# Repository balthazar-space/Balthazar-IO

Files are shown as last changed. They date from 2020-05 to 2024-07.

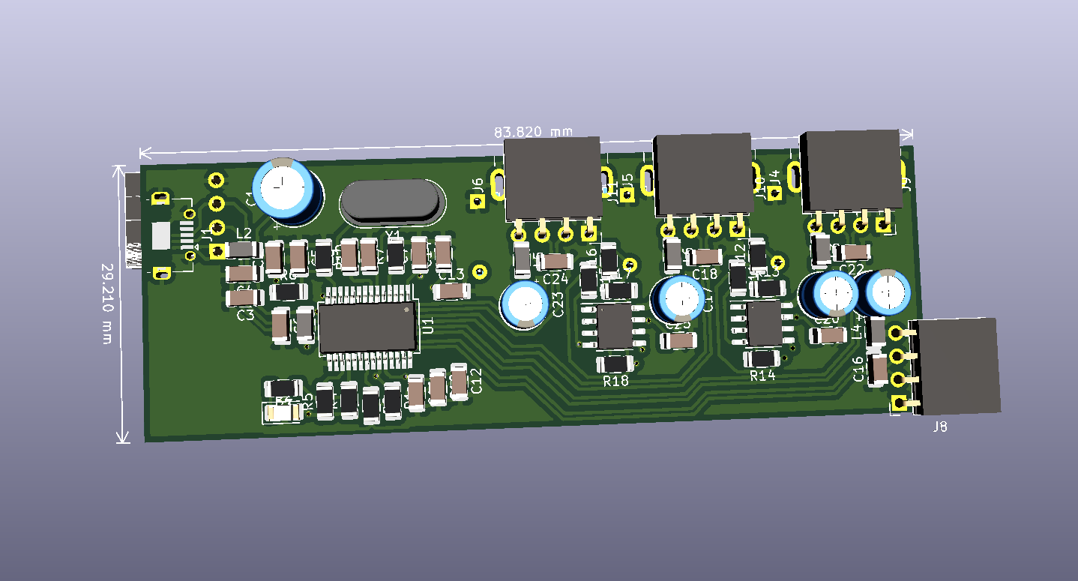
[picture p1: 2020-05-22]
images/BalthazarIO_3.png

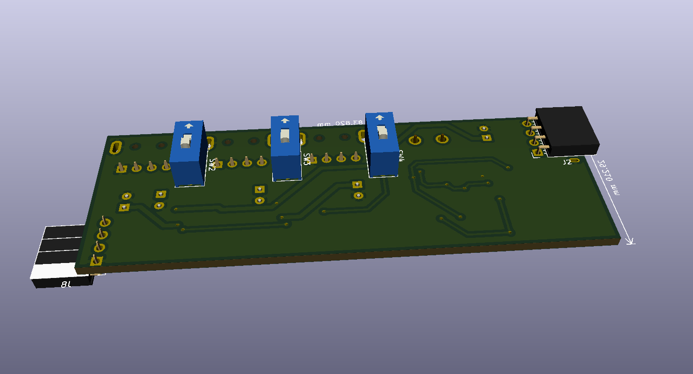
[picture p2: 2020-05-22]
images/BalthazarIO_6.png

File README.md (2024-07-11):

# Balthazar

Open-hardware laptop computer modules description and concept.

These are electronic schematic modules as presented at https://balthazar.space/wiki/Balthazar with the main aim for team access. See the [main repository](https://github.com/balthazar-space/balthazar) for other designs.

# Balthazar IO

BalthazarIO module is a simple USB2.0 four-port hub for the internal devices: keyboard and touchpad, webcam and optional audiocard. Additional simplification and pcb size reduction was done recently.

IO-board (here) means connectivity with peripheral devices. These can be seen as on-board and out-board. On-board Balthazar devices include: combined usb1.1 keyboard + trackpad, usb2.0 webcam and optional audio-card. 

Since we are targeting the mini-computer family of systems (Raspberry PI. Banana PI, Orange PI, ...) - USB is the usual solution for this. 

A simple usb 2.0 hub is enough, so a very ubiquitous usb hub chip was chosen. Main mini-computer board usually provides a much better hub for 4 downstream usb devices. At this point this is still mainly USB 2.x - slowly moving to usb3.x.

Mass storage / system disk - microSD – and especially versions of SSD (sata or pcie) – should be plugged to usb3.x directly (via usb adapter).

KiCad 5.1.5 files are uploaded here as well as the drawings and pictures.

## License

All resources licensed under the CERN Open Hardware Licence CERN-OHL W V.2.0

Version 2.0 of the CERN-OHL introduces three variants of the licence – strongly (S) reciprocal, weakly (W) reciprocal and permissive (P) – which aim to address specific constraints caused by different collaboration models currently used in open-hardware projects. 

The first two variants mean that if any product is made using an open hardware design, the design of that product, including any improvements or modifications, should be made available under the same licence as that of the original product. Permissive licences do not impose this condition.

See the [LICENSE.md](./LICENSE.md) file for more information.

## Funding

This project is funded through the [NGI Zero Entrust Fund](https://nlnet.nl/entrust), a fund
established by [NLnet](https://nlnet.nl) with financial support from the European Commission's
[Next Generation Internet](https://ngi.eu) program. Learn more on the [NLnet project page](https://nlnet.nl/project/Balthazar-Casing/).

[NLNet foundation logo](https://nlnet.nl)
[NGI0 Entrust Logo](https://nlnet.nl/entrust)

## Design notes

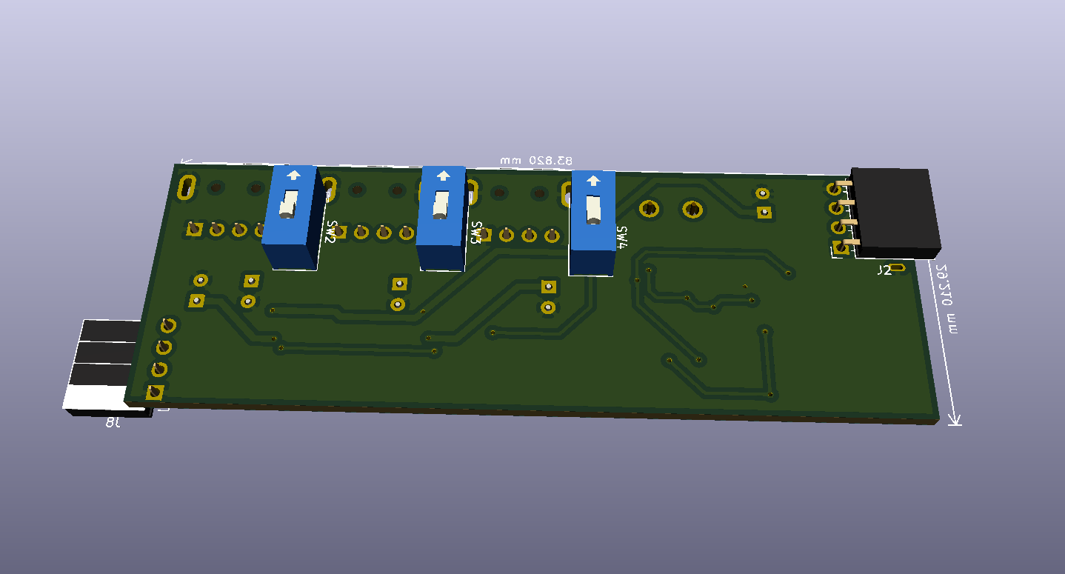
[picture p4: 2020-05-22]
images/BalthazarIO_4.png

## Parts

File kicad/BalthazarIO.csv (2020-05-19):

Reference | Value | Footprint | Datasheet
C7 | 100n | Capacitor_SMD:C_1206_3216Metric | ~
C6 | 100n | Capacitor_SMD:C_1206_3216Metric | ~
C4 | 100n | Capacitor_SMD:C_1206_3216Metric | ~
L1 | 10uH | Inductor_SMD:L_1206_3216Metric
C11 | 100n | Capacitor_SMD:C_1206_3216Metric | ~
C12 | 100n | Capacitor_SMD:C_1206_3216Metric | ~
C13 | 100n | Capacitor_SMD:C_1206_3216Metric | ~
C14 | 100n | Capacitor_SMD:C_1206_3216Metric | ~
R7 | 680 | Resistor_SMD:R_1206_3216Metric | ~
Y1 | Crystal 12MHz | Crystal:Crystal_HC50_Vertical | ~
C8 | 22-33p | Capacitor_SMD:C_1206_3216Metric | ~
C9 | 22-33p | Capacitor_SMD:C_1206_3216Metric | ~
J5 | USB_A | Connector_USB:USB_A_CNCTech_1001-011-01101_Horizontal | ~
J4 | USB_A | Connector_USB:USB_A_CNCTech_1001-011-01101_Horizontal | ~
J6 | USB_A | Connector_USB:USB_A_CNCTech_1001-011-01101_Horizontal | ~
J3 | USB_A | Connector_USB:USB_A_CNCTech_1001-011-01101_Horizontal | ~
C5 | 0.1-1u | Capacitor_SMD:C_1206_3216Metric | ~
R5 | 10K-510K-1M | Resistor_SMD:R_1206_3216Metric | ~
R4 | 100K | Resistor_SMD:R_1206_3216Metric | ~
R3 | 1K | Resistor_SMD:R_1206_3216Metric | ~
D2 | LED GREEN | LED_SMD:LED_1206_3216Metric | ~
R1 | 5K1 | Resistor_SMD:R_1206_3216Metric | ~
R2 | 10K | Resistor_SMD:R_1206_3216Metric | ~
C2 | 1u | Capacitor_SMD:C_1206_3216Metric | ~
C1 | 330uF | Capacitor_THT:CP_Radial_D8.0mm_P2.50mm | ~
F1 | 500mA | Fuse:Fuse_1206_3216Metric | ~
C18 | 100n | Capacitor_SMD:C_1206_3216Metric | ~
C17 | 100uF | Capacitor_THT:CP_Radial_D6.3mm_P2.50mm | ~
C16 | 100n | Capacitor_SMD:C_1206_3216Metric | ~
C15 | 100uF | Capacitor_THT:CP_Radial_D6.3mm_P2.50mm | ~
J2 | Conn_01x04_Female | Connector_PinSocket_2.54mm:PinSocket_1x04_P2.54mm_Horizontal | ~
C10 | 10uF | Capacitor_SMD:C_1206_3216Metric | ~
C3 | 10uF | Capacitor_SMD:C_1206_3216Metric | ~
L4 | 10uH | Inductor_SMD:L_1206_3216Metric
L5 | 10uH | Inductor_SMD:L_1206_3216Metric
L3 | 10uH | Inductor_SMD:L_1206_3216Metric
R6 | 10K | Resistor_SMD:R_1206_3216Metric | ~
R10 | 47K | Resistor_SMD:R_1206_3216Metric | ~
U2 | AT24CS02-XHM | Package_SO:SOP-8_3.9x4.9mm_P1.27mm | http://ww1.microchip.com/downloads/en/DeviceDoc/Atmel-8815-SEEPROM-AT24CS01-02-Datasheet.pdf
C19 | 100n | Capacitor_SMD:C_1206_3216Metric | ~
R9 | 10K | Resistor_SMD:R_1206_3216Metric | ~
L6 | 10uH | Inductor_SMD:L_1206_3216Metric
C24 | 100n | Capacitor_SMD:C_1206_3216Metric | ~
C23 | 100uF | Capacitor_THT:CP_Radial_D6.3mm_P2.50mm | ~
C22 | 100n | Capacitor_SMD:C_1206_3216Metric | ~
C21 | 100uF | Capacitor_THT:CP_Radial_D6.3mm_P2.50mm | ~
J1 | USB_B_Micro | Connector_USB:USB_Micro-AB_Molex_47590-0001 | ~
L2 | ferrite | Inductor_SMD:L_1206_3216Metric
U3 | AIC1526-0 | Package_SO:SOP-8_3.9x4.9mm_P1.27mm
C20 | 100n | Capacitor_SMD:C_1206_3216Metric | ~
R14 | 10K | Resistor_SMD:R_1206_3216Metric | ~
R13 | 10K | Resistor_SMD:R_1206_3216Metric | ~
R12 | 100K | Resistor_SMD:R_1206_3216Metric | ~
R11 | 100K | Resistor_SMD:R_1206_3216Metric | ~
SW1 | SW_DIP_x01 | Button_Switch_THT:SW_DIP_SPSTx01_Slide_9.78x4.72mm_W7.62mm_P2.54mm | ~
SW2 | SW_DIP_x01 | Button_Switch_THT:SW_DIP_SPSTx01_Slide_9.78x4.72mm_W7.62mm_P2.54mm | ~
U4 | AIC1526-0 | Package_SO:SOP-8_3.9x4.9mm_P1.27mm
C25 | 100n | Capacitor_SMD:C_1206_3216Metric | ~
R18 | 10K | Resistor_SMD:R_1206_3216Metric | ~
R17 | 10K | Resistor_SMD:R_1206_3216Metric | ~
R16 | 100K | Resistor_SMD:R_1206_3216Metric | ~
R15 | 100K | Resistor_SMD:R_1206_3216Metric | ~
SW3 | SW_DIP_x01 | Button_Switch_THT:SW_DIP_SPSTx01_Slide_9.78x4.72mm_W7.62mm_P2.54mm | ~
SW4 | SW_DIP_x01 | Button_Switch_THT:SW_DIP_SPSTx01_Slide_9.78x4.72mm_W7.62mm_P2.54mm | ~
U1 | GL850G-28pin | Package_SO:SSOP-28_5.3x10.2mm_P0.65mm
J10 | USB_01x04 | Connector_PinSocket_2.54mm:PinSocket_1x04_P2.54mm_Horizontal | ~
J11 | USB_01x04 | Connector_PinSocket_2.54mm:PinSocket_1x04_P2.54mm_Horizontal | ~
J9 | USB_01x04 | Connector_PinSocket_2.54mm:PinSocket_1x04_P2.54mm_Horizontal | ~
J8 | USB_01x04 | Connector_PinSocket_2.54mm:PinSocket_1x04_P2.54mm_Horizontal | ~
J7 | Conn_01x04_Male | Connector_PinHeader_2.54mm:PinHeader_1x04_P2.54mm_Horizontal | ~

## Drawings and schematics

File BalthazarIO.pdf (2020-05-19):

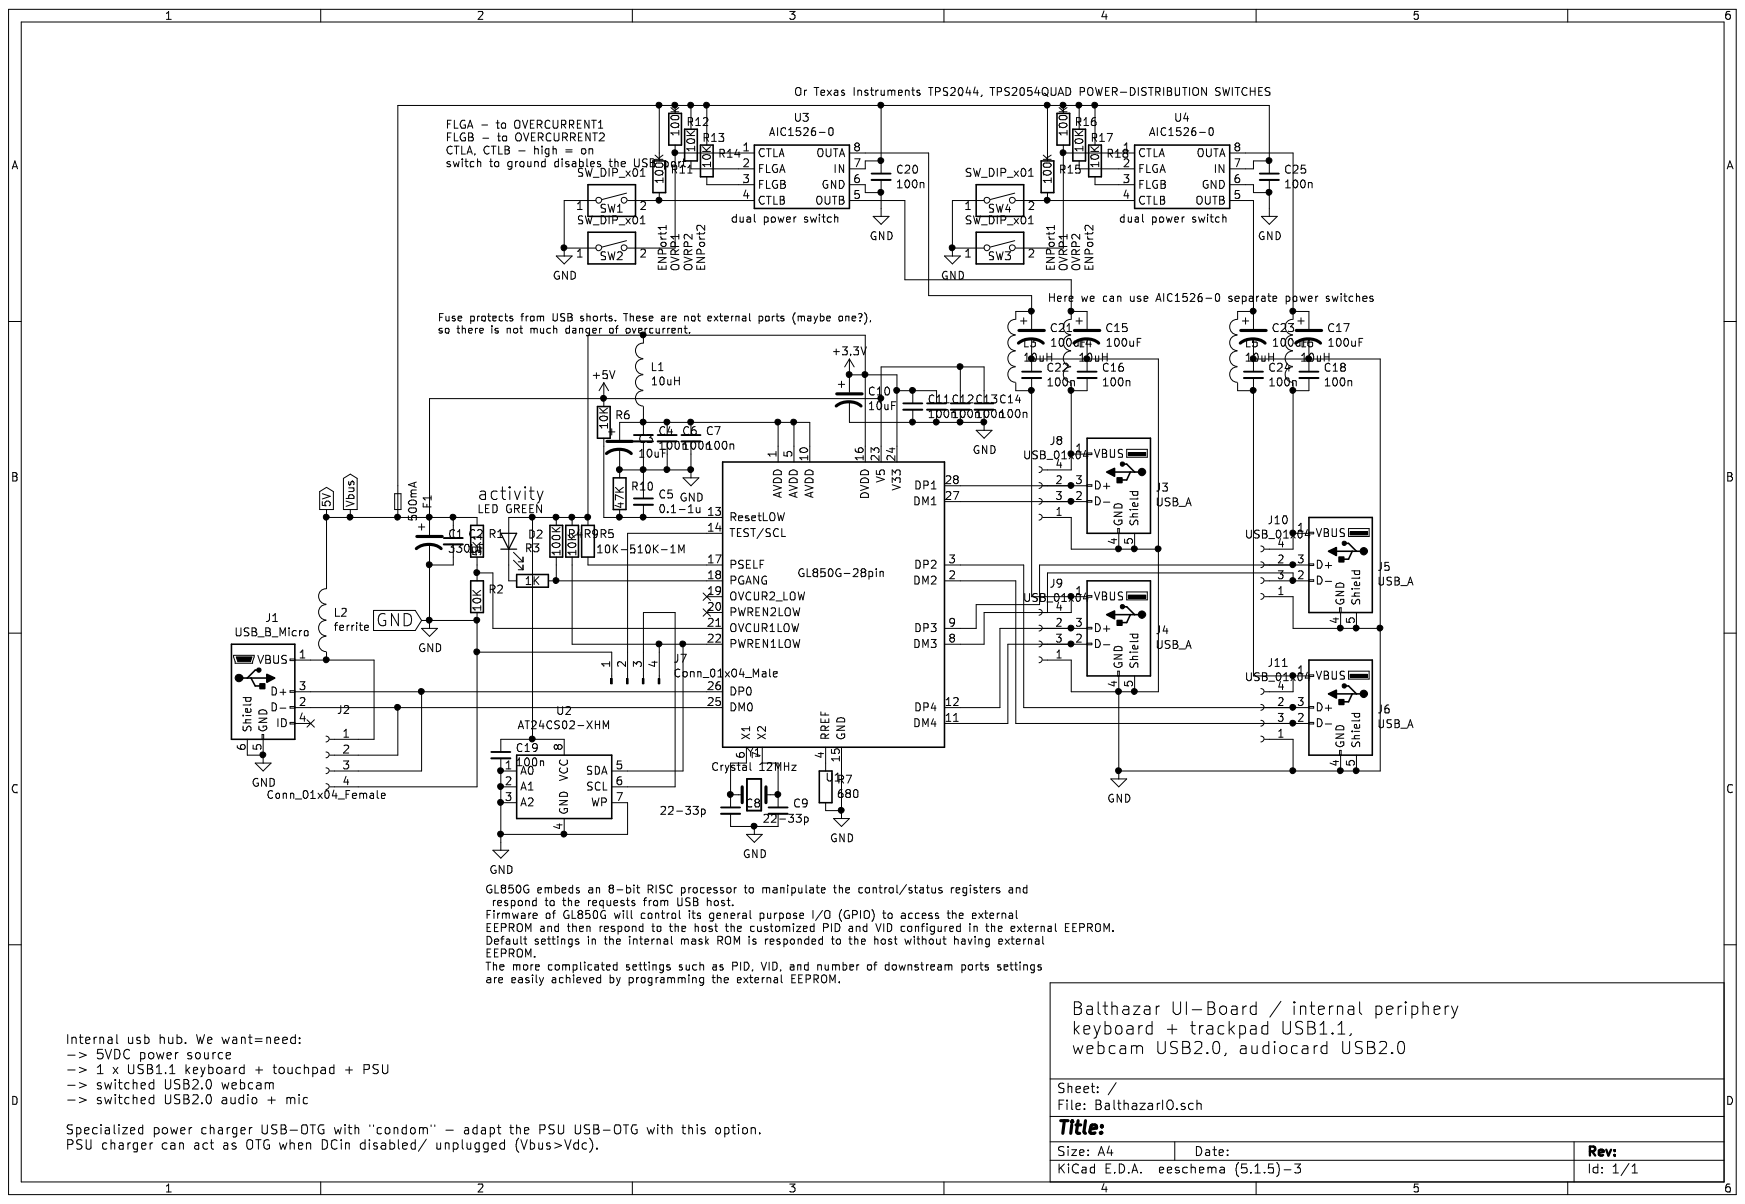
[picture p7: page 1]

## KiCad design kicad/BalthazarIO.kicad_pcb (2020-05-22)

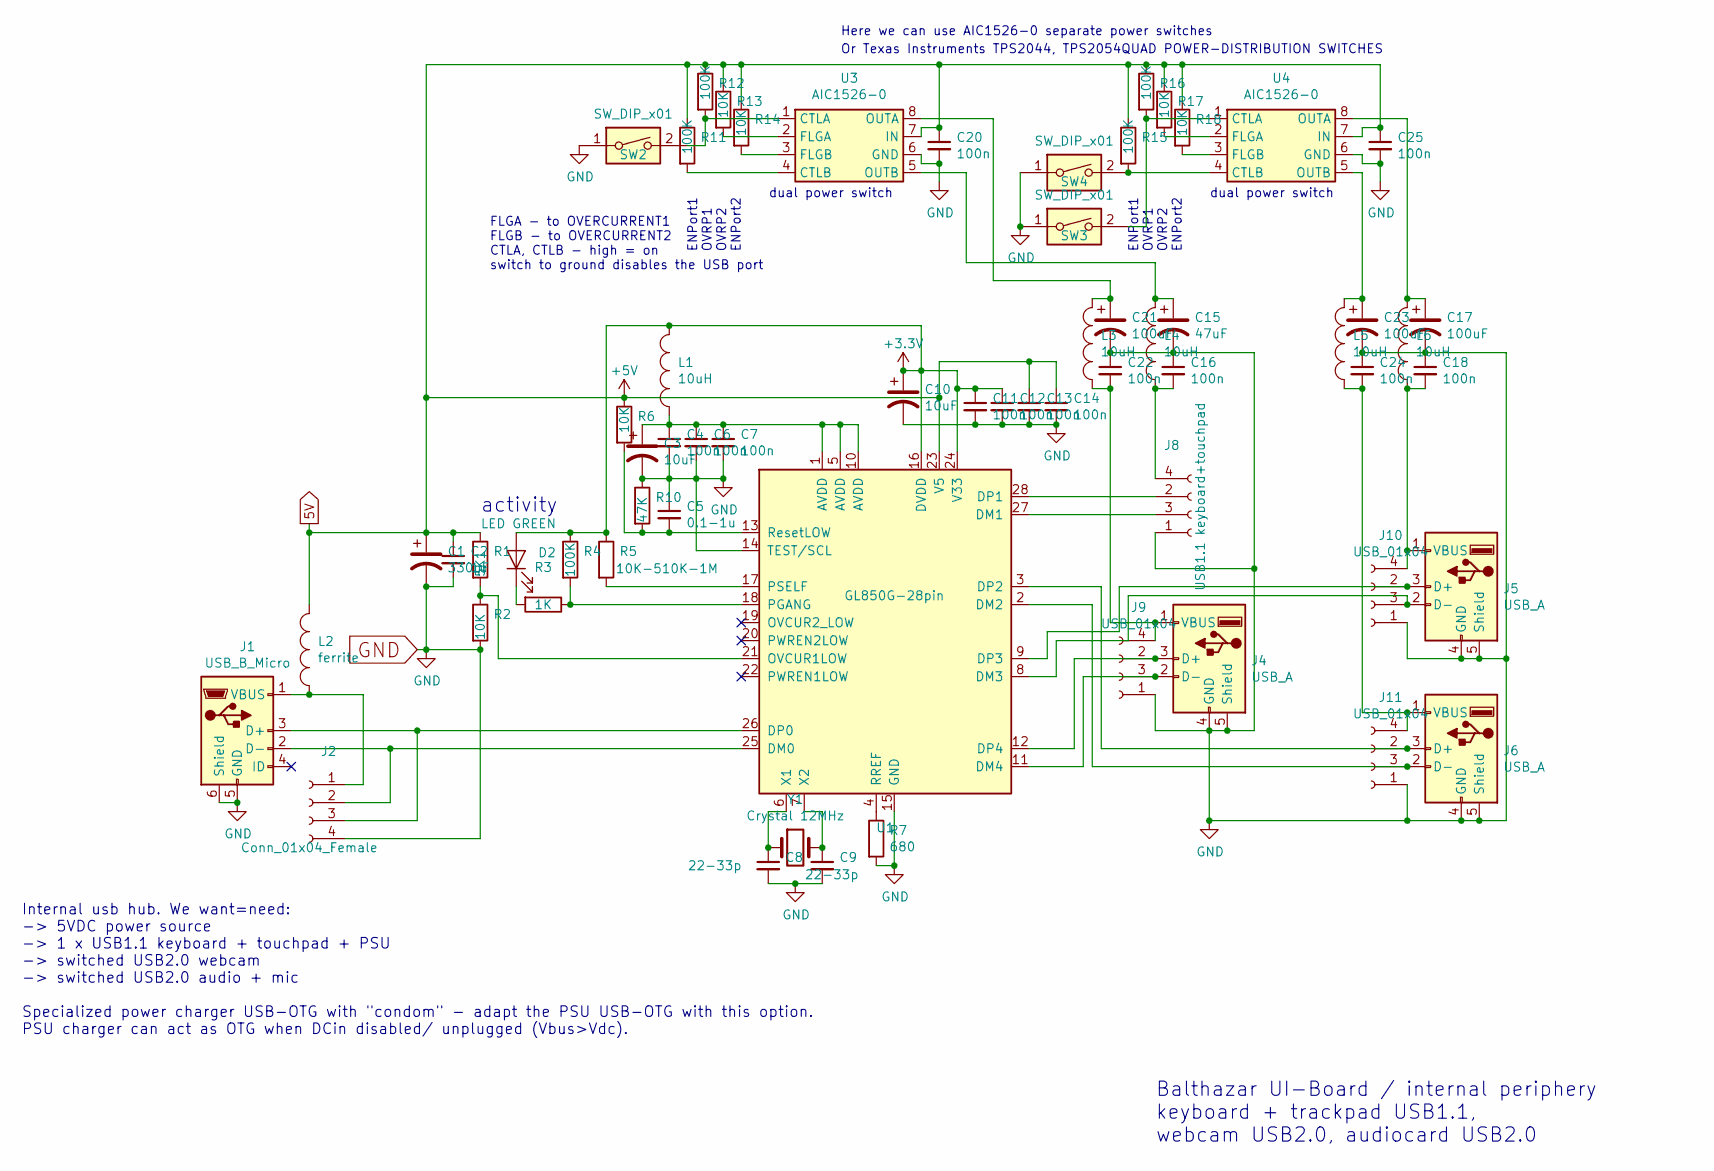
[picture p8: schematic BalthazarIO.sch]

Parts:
C1: 330uF; CP_Radial_D6.3mm_P2.50mm
C2: 1u; C_1206_3216Metric
C3, C10: 10uF; C_1206_3216Metric
C4, C6, C7, C11, C12, C13, C14, C16, C18, C20, C22, C24, C25: 100n; C_1206_3216Metric
C5: 0.1-1u; C_1206_3216Metric
C8, C9: 22-33p; C_1206_3216Metric
C15: 47uF; CP_Radial_D5.0mm_P2.50mm
C17, C21, C23: 100uF; CP_Radial_D5.0mm_P2.50mm
D2: LED GREEN; LED_1206_3216Metric
J1: USB_B_Micro; USB_Micro-AB_Molex_47590-0001
J2: Conn_01x04_Female; PinSocket_1x04_P2.54mm_Horizontal
J4, J5, J6: USB_A; USB_A_CNCTech_1001-011-01101_Horizontal
J8: USB1.1 keyboard+touchpad; PinSocket_1x04_P2.54mm_Horizontal
J9, J10, J11: USB_01x04; PinSocket_1x04_P2.54mm_Horizontal
L1, L3, L4, L5, L6: 10uH; L_1206_3216Metric
L2: ferrite; L_1206_3216Metric
R1: 5K1; R_1206_3216Metric
R2, R6, R13, R14, R17, R18: 10K; R_1206_3216Metric
R3: 1K; R_1206_3216Metric
R4, R11, R12, R15, R16: 100K; R_1206_3216Metric
R5: 10K-510K-1M; R_1206_3216Metric
R7: 680; R_1206_3216Metric
R10: 47K; R_1206_3216Metric
SW2, SW3, SW4: SW_DIP_x01; SW_DIP_SPSTx01_Slide_9.78x4.72mm_W7.62mm_P2.54mm
U1: GL850G-28pin; SSOP-28_5.3x10.2mm_P0.65mm
U3, U4: AIC1526-0; SOP-8_3.9x4.9mm_P1.27mm
Y1: Crystal 12MHz; Crystal_HC50_Vertical

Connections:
5V: C1.1, C2.1, C13.1, C14.1, C20.1, C25.1, L2.2, R1.1, R6.1, R11.1, R12.1, R13.1, R14.1, R15.1, R16.1, R17.1, R18.1, U1.23 (V5), U3.7 (IN), U4.7 (IN)
+3V3: C10.1, C11.1, C12.1, D2.2 (A), L1.2, R4.1, R5.1, U1.16 (DVDD), U1.24 (V33)
GND: C1.2, C2.2, C3.2, C4.2, C5.1, C6.2, C7.2, C8.2, C9.2, C10.2, C11.2, C12.2, C13.2, C14.2, C15.2, C16.1, C17.2, C18.1, C20.2, C21.2, C22.1, C23.2, C24.1, C25.2, J1.5 (GND), J1.6 (Shield), J2.4, J4.4 (GND), J4.5 (Shield), J5.4 (GND), J5.5 (Shield), J6.4 (GND), J6.5 (Shield), J8.1 (Vbus), J9.1 (Vbus), J10.1 (Vbus), J11.1 (Vbus), R2.2, R7.2, R10.1, SW2.1, SW3.1, SW4.1, U1.14 (TEST/SCL), U1.15 (GND), U3.6 (GND), U4.6 (GND)
unnamed: C3.1, C4.1, C6.1, C7.1, L1.1, U1.1 (AVDD), U1.5 (AVDD), U1.10 (AVDD)
unnamed: C5.2, R6.2, R10.2, U1.13 (ResetLOW)
unnamed: C8.1, U1.6 (X1), Y1.1
unnamed: C9.1, U1.7 (X2), Y1.2
unnamed: C15.1, L4.2, U3.5 (OUTB)
unnamed: C16.2, J8.4 (gnd), L4.1
unnamed: C17.1, L6.2, U4.8 (OUTA)
unnamed: C18.2, J5.1 (VBUS), J10.4 (gnd), L6.1
unnamed: C21.1, L3.2, U3.8 (OUTA)
unnamed: C22.2, J4.1 (VBUS), J9.4 (gnd), L3.1
unnamed: C23.1, L5.2, U4.5 (OUTB)
unnamed: C24.2, J6.1 (VBUS), J11.4 (gnd), L5.1
unnamed: D2.1 (K), R3.2
unnamed: J1.1 (VBUS), J2.1, L2.1
unnamed: J1.2 (D-), J2.2, U1.25 (DM0)
unnamed: J1.3 (D+), J2.3, U1.26 (DP0)
unnamed: J4.2 (D-), J9.3, U1.11 (DM4)
unnamed: J4.3 (D+), J9.2, U1.12 (DP4)
unnamed: J8.2, U1.28 (DP1)
unnamed: J8.3, U1.27 (DM1)
unnamed: J5.3 (D+), J10.2, U1.9 (DP3)
unnamed: J5.2 (D-), J10.3, U1.8 (DM3)
unnamed: J6.3 (D+), J11.2, U1.3 (DP2)
unnamed: J6.2 (D-), J11.3, U1.2 (DM2)
unnamed: R1.2, R2.1, U1.21 (OVCUR1LOW)
unnamed: R3.1, R4.2, U1.18 (PGANG)
unnamed: R5.2, U1.17 (PSELF)
unnamed: R7.1, U1.4 (RREF)
unnamed: R11.2, U3.4 (CTLB)
unnamed: R12.2, SW2.2, U3.1 (CTLA)
unnamed: R13.2, U3.2 (FLGA)
unnamed: R14.2, U3.3 (FLGB)
unnamed: R15.2, SW4.2, U4.4 (CTLB)
unnamed: R16.2, SW3.2, U4.1 (CTLA)
unnamed: R17.2, U4.2 (FLGA)
unnamed: R18.2, U4.3 (FLGB)

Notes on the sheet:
Balthazar UI-Board / internal periphery keyboard + trackpad USB1.1, webcam USB2.0, audiocard USB2.0
activity
Internal usb hub. We want=need: -> 5VDC power source -> 1 x USB1.1 keyboard + touchpad + PSU -> switched USB2.0 webcam -> switched USB2.0 audio + mic Specialized power charger USB-OTG with "condom" - adapt the PSU USB-OTG with this option. PSU charger can act as OTG when DCin disabled/ unplugged (V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
Here we can use AIC1526-0 separate power switches
ENPort1 OVRP1 OVRP2 ENPort2
dual power switch
Or Texas Instruments TPS2044, TPS2054QUAD POWER-DISTRIBUTION SWITCHES
FLGA - to OVERCURRENT1 FLGB - to OVERCURRENT2 CTLA, CTLB - high = on switch to ground disables the USB port

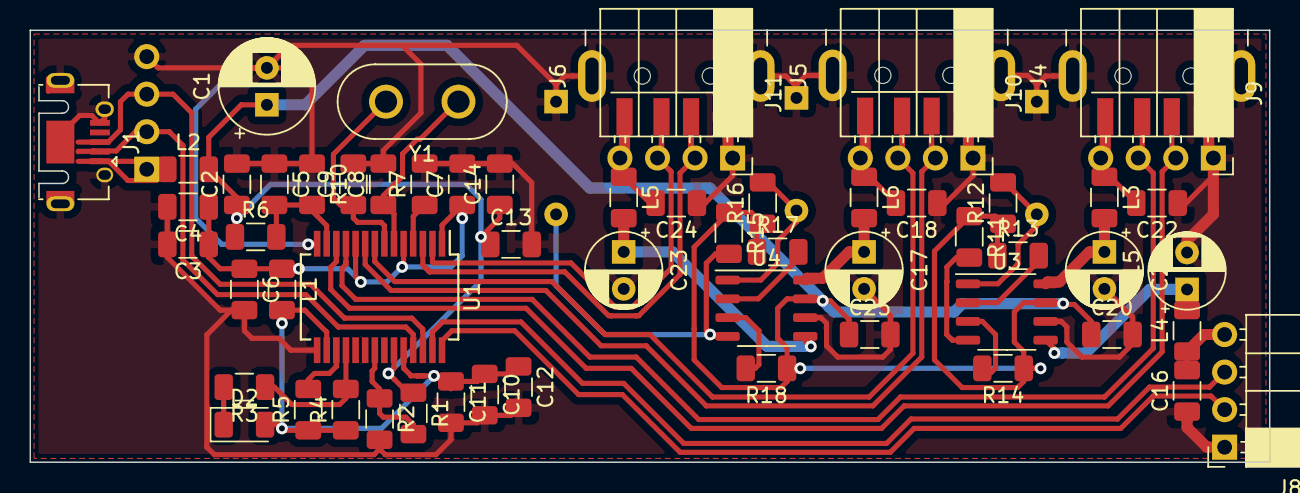
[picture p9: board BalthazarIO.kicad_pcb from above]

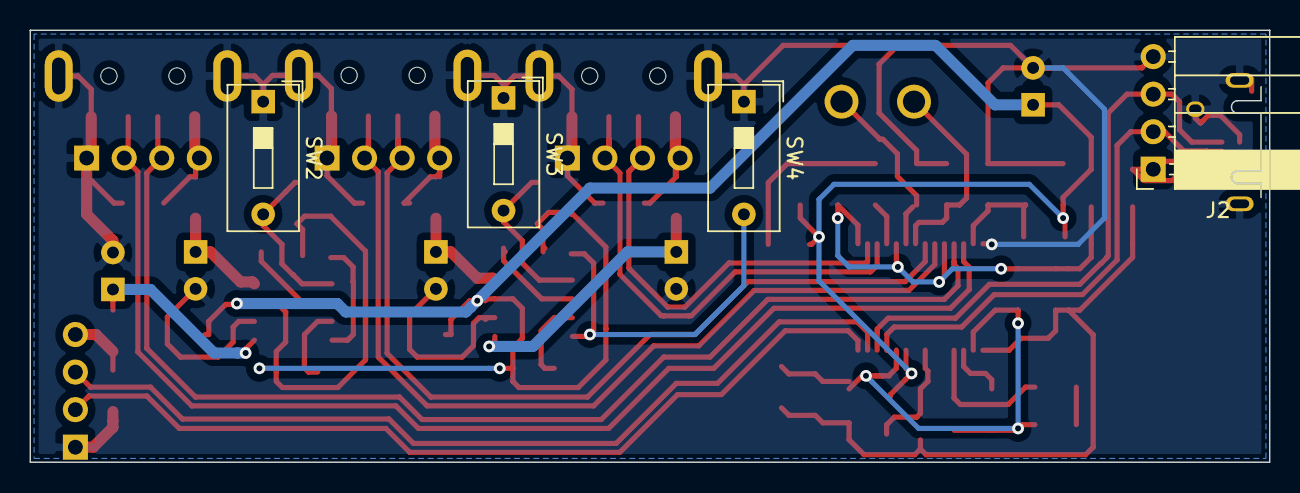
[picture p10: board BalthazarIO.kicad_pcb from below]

Board: 2 copper layers, 83.8 x 29.2 mm, 63 parts (4 on the bottom side), 39 nets.
